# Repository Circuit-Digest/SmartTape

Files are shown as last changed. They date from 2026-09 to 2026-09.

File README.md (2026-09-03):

# SmartTape - Digital Measuring Tool

```
  ███████╗███╗   ███╗ █████╗ ██████╗ ████████╗    ████████╗ █████╗ ██████╗ ███████╗
  ██╔════╝████╗ ████║██╔══██╗██╔══██╗╚══██╔══╝    ╚══██╔══╝██╔══██╗██╔══██╗██╔════╝
  ███████╗██╔████╔██║███████║██████╔╝   ██║          ██║   ███████║██████╔╝█████╗  
  ╚════██║██║╚██╔╝██║██╔══██║██╔══██╗   ██║          ██║   ██╔══██║██╔═══╝ ██╔══╝  
  ███████║██║ ╚═╝ ██║██║  ██║██║  ██║   ██║          ██║   ██║  ██║██║     ███████╗
  ╚══════╝╚═╝     ╚═╝╚═╝  ╚═╝╚═╝  ╚═╝   ╚═╝          ╚═╝   ╚═╝  ╚═╝╚═╝     ╚══════╝
```







A pocket-size multi-mode digital laser measuring tape device built around the **STM32G491CEU6** 32-bit ARM Cortex-M4F microcontroller. Featuring **ST VL53L4CX 6.0-meter Time-of-Flight (ToF) ranging**, **Murata SCL3300 3-axis inclinometer level sensing**, an **animated 60FPS smartwatch-style carousel UI**, and **non-volatile internal Flash memory persistence**.

---

## Key Features

* **8 Comprehensive Operating Modes**:
  1. **Distance Meter (`DIST`)**: Real-time continuous ToF distance measurement (up to 6.0 meters / 600 cm) with live roll & pitch level alignment bars.
  2. **Spirit Level (`LEVEL`)**: 2D digital bubble level + 3D pitch/roll angle readout ($0.01^\circ$ resolution) and temperature display.
  3. **Height Meter (`HEIGHT`)**: Pythagoras indirect height measurement with automatic ToF vertical mounting offset & 2-point empirical tilt calibration.
  4. **Area Calculator (`AREA`)**: 2-shot interactive room area calculation ($L \times W \implies \text{cm}^2 / \text{m}^2$).
  5. **Volume Calculator (`VOLUME`)**: 3-shot 3D space volume calculation ($L \times W \times H \implies \text{cm}^3 / \text{m}^3$).
  6. **Cylinder Meter (`CYLINDER`)**: Pipe and tank volume calculation ($\pi \cdot R^2 \cdot H$).
  7. **Max / Min Tracker (`MAXMIN`)**: Dynamic real-time minimum and maximum distance boundary tracker.
  8. **Memory Log (`MEMORY`)**: Persistent 10-slot measurement record buffer.

* **ST VL53L4CX Ranging Optimization**:
  - **Multi-Target Histogram Ranging**: Penetrates transparent glass windows and filters out foreground obstacles to lock onto background target walls.
  - **Cover Glass Crosstalk Cancellation**: Cancels internal VCSEL reflections inside protective enclosure windows.

* **Power Management & Dual Auto-Wakeup**:
  - Hardware `XSHUT` zero-current shutdown.
  - 3-Minute Inactivity Auto-Sleep.
  - SCL3300 Motion Pick-up ($\Delta G > 0.03g$) & Encoder Turn/Press instant auto-wakeup.

---

## User Controls & Navigation Guide

### 1. Hardware Controls Overview
- **Rotary Encoder Knob (Hongyan RS11)**: Spring-return $\pm 15^\circ$ rotation knob (flicks CW / CCW and snaps back to center).
- **Center Push Button Switch (SW)**: Integrated tactile push-button (`PB14`).

---

### 2. Main Screen & Measurement Navigation

| Action / Gesture | Hardware Trigger | Mode / Context | Function / Operation |
| :--- | :--- | :--- | :--- |
| **Rotate Knob (CW / CCW)** | Flick Knob $\pm 15^\circ$ | **Carousel Menu** | Scroll through 8 measurement modes (smooth 60FPS animation). |
| **Rotate Knob (CW / CCW)** | Flick Knob $\pm 15^\circ$ | **Memory Log (`MEMORY`)** | Browse through 10 saved measurement history records. |
| **Single-Press** | Press Button | **Carousel Menu** | **Select & Enter** highlighted measurement mode. |
| **Single-Press** | Press Button | **`DIST` / `HEIGHT` Modes** | **Toggle `HOLD` Mode** (freezes measurement reading & angle; turns OFF laser). |
| **Single-Press** | Press Button | **`AREA` Mode** | Take Shot 1 (Length) $\rightarrow$ Take Shot 2 (Width) $\rightarrow$ Calculate Area ($\text{cm}^2 / \text{m}^2$). |
| **Single-Press** | Press Button | **`VOLUME` Mode** | Take Shot 1 (Length) $\rightarrow$ Shot 2 (Width) $\rightarrow$ Shot 3 (Height) $\rightarrow$ Calculate Volume ($\text{cm}^3 / \text{m}^3$). |
| **Single-Press** | Press Button | **`MAXMIN` Mode** | Reset Min / Max distance trackers. |
| **Double-Press** | Quick 2x Click ($< 400\text{ms}$) | **Any Mode / Settings** | **Global BACK** $\rightarrow$ Return immediately to Main Carousel Menu. |
| **Long-Press** | Hold Button ($> 800\text{ms}$) | **Any Screen** | **Toggle Settings Menu** overlay. |
| **Press + Twist** | Hold Switch + Rotate Knob | **Any Active Mode** | **Chorded Gesture BACK** $\rightarrow$ Return immediately to Main Carousel Menu. |

---

### 3. Settings Menu Navigation & Value Editing

```
[Main Carousel] ──(Long-Press >800ms)──> [Settings Overlay]
                                                │
                          Rotate Knob ───> Scroll items (UNIT, DATUM, OFFSET)
                                                │
                          Single-Press ──> Enter ITEM EDIT MODE (SETTINGS [EDIT])
                                                │
                          Rotate Knob ───> Fast-adjust value (0.1cm steps for offset)
                                                │
                    Single or Double-Press ─> Confirm & Auto-Save to Flash Page 255
```

| Action / Gesture | Context | Function |
| :--- | :--- | :--- |
| **Rotate Knob** | Settings List Mode | Scroll between items (`0: UNIT`, `1: DATUM`, `2: REAR OFFSET`). |
| **Single-Press** | Settings List Mode | Enter **ITEM EDIT MODE** (`SETTINGS [EDIT]`). Value displays in `< angle brackets >`. |
| **Rotate Knob** | **ITEM EDIT MODE** | **Change Value**: <br>• **`UNIT`**: `CM` $\leftrightarrow$ `MM` $\leftrightarrow$ `M` $\leftrightarrow$ `INCH` <br>• **`DATUM`**: `REAR` $\leftrightarrow$ `FRONT` <br>• **`OFFSET`**: Adjust body length in **0.1 cm (1 mm)** steps! |
| **Single-Press** | **ITEM EDIT MODE** | Confirm new value, **Save to NVM Flash Page 255**, and return to Settings List. |
| **Double-Press** | **ITEM EDIT MODE** | Confirm value, Save to Flash, and return to Settings List. |
| **Double-Press** | Settings List Mode | Exit Settings and return to Main Carousel Menu. |

---

## Hardware Pinout Mapping

| Component | Signal | STM32G4 Pin | Description |
| :--- | :--- | :--- | :--- |
| **MCU** | Main Core | STM32G491CEU6 | 170 MHz ARM Cortex-M4F, 512KB Flash, 128KB RAM |
| **OLED Display** | I2C2 SDA | `PA8` | 1.3" 128x64 SH1106 OLED (Address `0x3C`) |
| | I2C2 SCL | `PA9` | |
| **ToF Sensor** | I2C1 SCL | `PA15` | ST VL53L4CX 6.0m ToF Sensor (Address `0x52`) |
| | I2C1 SDA | `PB7` | |
| | ToF INT | `PC10` | Hardware Interrupt Line |
| | ToF XSHUT | `PC11` | Hardware Zero-Power Shutdown Control |
| **Inclinometer** | SPI1 CS | `PA3` | Murata / VTI SCL3300 3-Axis Inclinometer |
| | SPI1 SCK | `PA5` | SPI Clock |
| | SPI1 MISO | `PA6` | SPI Master In Slave Out |
| | SPI1 MOSI | `PA7` | SPI Master Out Slave In |
| **Laser Diode** | EN | `PA4` | CAT4002A Constant-Current Laser Driver |
| **Battery Monitor**| ADC3 CH1 | `PB1` | 1S Li-Ion Voltage Divider ($100\text{ k}\Omega / 100\text{ k}\Omega$) |
| **Rotary Encoder** | SW | `PB14` | Hongyan RS11 Spring-Return Switch |
| | Phase A | `PB12` | Encoder Phase A |
| | Phase B | `PB13` | Encoder Phase B |

---

## Software & Driver Architecture

- **Toolchain**: STM32CubeIDE (GCC ARM Embedded Toolchain).
- **HAL Drivers**: STM32G4 HAL Driver Package + ST VL53L4CX Ultra-Lite Driver (ULD).
- **Core Files**:
  - `Core/Src/main.c`: Main firmware logic, state machine, ToF filtering, calibration, and Flash storage.
  - `Core/Src/oled.c`: SH1106 OLED vector graphics, 7-segment font renderer, and 60FPS carousel engine.
  - `Core/Src/scl3300.c`: SPI driver and angle/acceleration conversion for Murata SCL3300.

---

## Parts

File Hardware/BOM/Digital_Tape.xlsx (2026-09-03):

Name | Description | Designator | Footprint | LibRef | Quantity
10 µF | CAP0603 X7R 10UF 20% 6.3V | C1, C3, C5, C14, C25 | CAP 0603_1608 | GMC10X7R106M6R3NT | 5
0.1 µF | CAP CER 0.1UF 16V X7R 0603 | C2, C4, C6, C7, C10, C12, C15, C16, C17, C18, C21, C22, C23, C24 | CAP 0603_1608 | CS0603KRX7R7BB104 | 14
1µF | CAP CER 1UF 10V Y5V 0603 | C8, C9, C11, C13, C26, C27 | CAP 0603_1608 | 0603ZG105ZAT2A | 6
8 pF | CAP CER 8PF 50V 0603 EPOXY | C19, C20 | CAP 0603_1608 | CGA3E2C0G1H080D080AD | 2
CUS10S30,H3F | DIODE SCHOTTKY 30V 1A USC | D1 | SOD323 | CUS10S30,H3F | 1
GG0402060R3C2P | TVS DIODE 6.5VWM 15.5VC 0402 | D2, D3 | 0402 | GG0402060R3C2P | 2
DIM_PAD |  | DP1, DP2 | DIM_PAD | DIM_PAD | 2
OLED_128X64_1.3_I2C | Non-Touch Graphic LCD Display Module Transmissive White OLED, Monochrome I2C 1.3 (33.02mm) 128 x 64 | DS1 | LCD_OLED_128X64_1.3_I2C | OLED_128X64_1.3_I2C | 1
TYPE-C_16PIN_2MD_(073) | DC-5V 5A Type C USB | J1 | SHOUHAN_TYPE-C_16PIN_2MD_(073) | TYPE-C_16PIN_2MD_(073) | 1
B2B-PH-K-S(LF)(SN) | Connector Header Through Hole 2 position 0.079 (2.00mm) | J2 | JST_B2B-PH-K-S(LF)(SN) | B2B-PH-K-S(LF)(SN) | 1
TSHC-103-D-171-16-264-F-LF | 6 Position Dual Row (3x2) 2.54mm Pitch Non-Shrouded Header | J3 | MLE_TSHC-103-D-171-16-264-F-LF | TSHC-103-D-171-16-264-F-LF | 1
RLD65NZN5 |  | LD1 | RLD65NZN5 | RLD65NZN5 | 1
PEC11R-4215F-S0024 | Incremental Encoder, 12 Mm, Contact Rating 10 Ma - 5 Vdc | MT1 | XDCR_PEC11R-4215F-S0024 | PEC11R-4215F-S0024 | 1
AO3401A | P-Channel MOSFET, 30 V, 4 A, -55 to 150 degC, 3-Pin SOT-23-3L, RoHS, Tape and Reel | Q1 | AO-SOT-23-3L_V | CMP-2000-05778-1 | 1
0 Ohms | RES SMD 56K OHM 0.1% 1/10W 0603, RES 0 OHM JUMPER 1/10W 0603 | R1, R10 | RES 0603_1608 | RT0603BRD0756KL, PA0603-R-070RL | 2
1 kOhms | RES SMD 1K OHM 0.1% 1/16W 0603 | R2, R9, R17 | RES 0603_1608 | CPF0603B1K0E | 3
10 kOhms | RES 10K OHM 0.1% 1/16W 0603 | R3, R8, R11, R13, R14, R15, R16 | RES 0603_1608 | RNCS0603BKE10K0 | 7
10 kOhms | RES SMD 10K OHM 0.1% 1/16W 0402 | R4 | RES 0402_1005 | RT0402BRE0710KL | 1
5.1 kOhms | RES 5.1K OHM 5% 1/10W 0603 | R5, R7 | RES 0603_1608 | RMCF0603JG5K10 | 2
100 kOhms | RES 100K OHM 0.1% 1/16W 0603 | R6, R18, R19 | RES 0603_1608 | RNCS0603BKE100K | 3
1.65 kOhms | RES 1.65K OHM 1% 1/10W 0603 | R12 | RES 0603_1608 | RC0603FR-071K65L | 1
3.74 kOhms | RES 3.74K OHM 0.5% 1/10W 0603 | R20 | RES 0603_1608 | RNCF0603DTE3K74 | 1
4.7 kOhms | RES 4.7K OHM 0.1% 1/5W 0603 | R21, R22 | RES 0603_1608 | RS73G1JTTD4701B | 2
EG1215AA | Slide Switch SPDT Surface Mount, Right Angle | S1 | SW_EG1215AA | EG1215AA | 1
TS-1088-AR02016 |  | SW1, SW2 | SW-SMD_L3.9-W3.0-P4.45 | TS-1088-AR02016 | 2
ROUND PAD 1.5MM |  | TP1, TP2 | ROUND PAD 1.5MM | ROUND PAD 1.5MM | 2
LD39200PU33R | 2 A high PSRR ultra low drop linear regulator with reverse current protection | U1 | SON_DFN6_3X3_STM | LD39200PU33R | 1
LTC4057ES5-4.2 | Linear Li-Ion Battery Charger with Thermal Regulation in ThinSOT | U2 | S_5_ADI | LTC4057ES5-4.2TRMPBF | 1
STM32G491CEU6 | Mainstream Arm Cortex-M4 MCU 170 MHz with 512 Kbytes of Flash memory, Math Accelerator, High Analog level integration | U3 | QFPN_491CEU6_STM | STM32G491CEU6 | 1
SCL3300-D01-10 | Description | U4 | SCL3300-D01-10_MUR | SCL3300-D01-10 | 1
VL53L4CXV0DH/1 | Time-of-Flight (ToF) sensor with extended range measurement | U5 | LGA12_STM | VL53L4CXV0DH1 | 1
CAT4002A | 12-bit, single-channel, ultra-low power DAC in 6-pin SC70 package for battery powered applications | U6 | CAT4002A | CAT4002A | 1
ECS-240-8-37B-CKY-TR | 24 MHz Â±10ppm Crystal 8pF 50 Ohms 4-SMD, No Lead | Y1 | XTAL_ECS-160-9-37-CKM-TR | ECS-240-8-37B-CKY-TR | 1

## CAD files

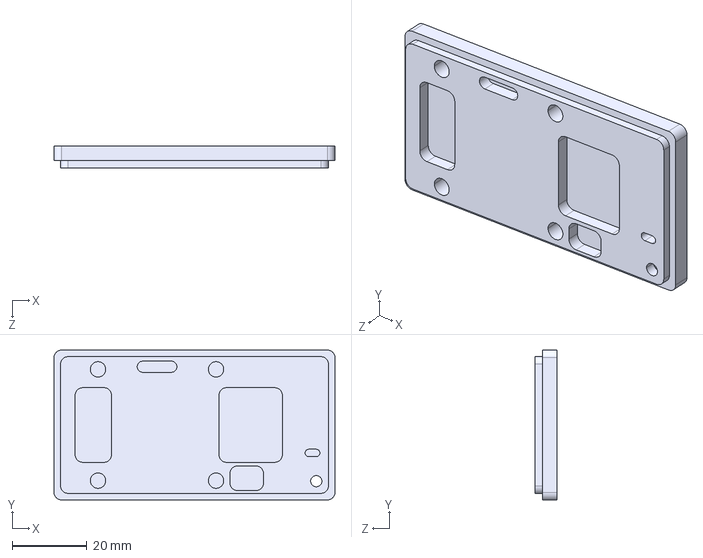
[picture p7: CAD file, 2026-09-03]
Hardware/CAD/SmartTape_BottomV1.STEP
75.0 x 40.0 x 6.00 mm

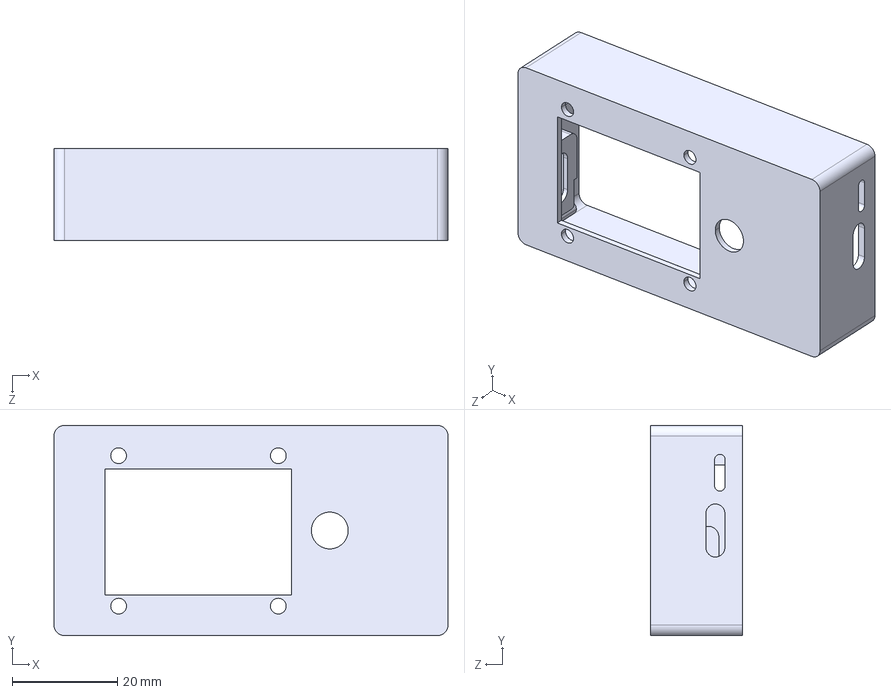
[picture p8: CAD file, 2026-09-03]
Hardware/CAD/SmartTape_TopV2.STEP
75.0 x 40.0 x 17.5 mm

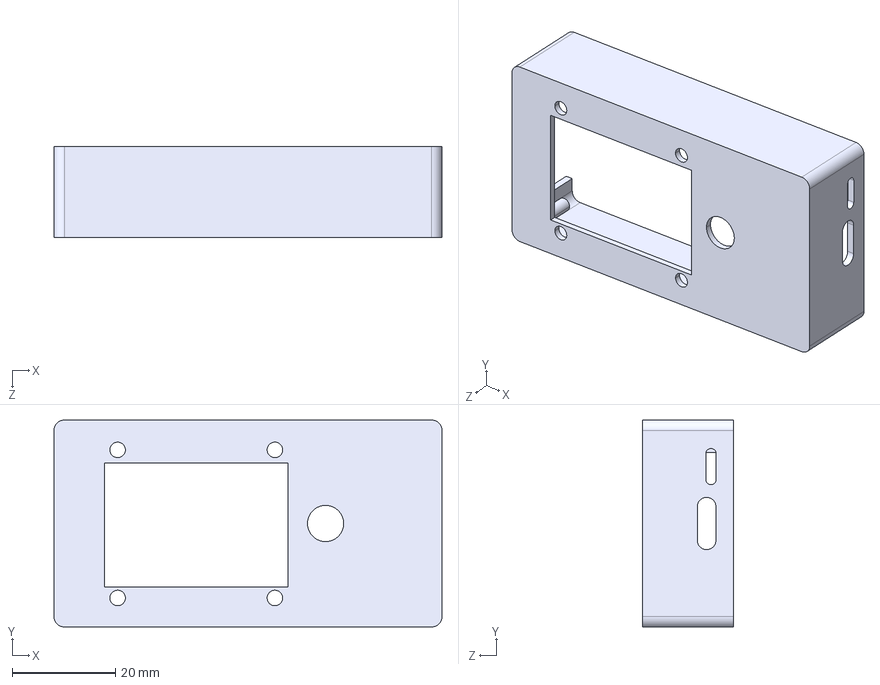
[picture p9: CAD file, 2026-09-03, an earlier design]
Hardware/CAD/SmartTape_TopV1.STEP
75.0 x 40.0 x 17.5 mm

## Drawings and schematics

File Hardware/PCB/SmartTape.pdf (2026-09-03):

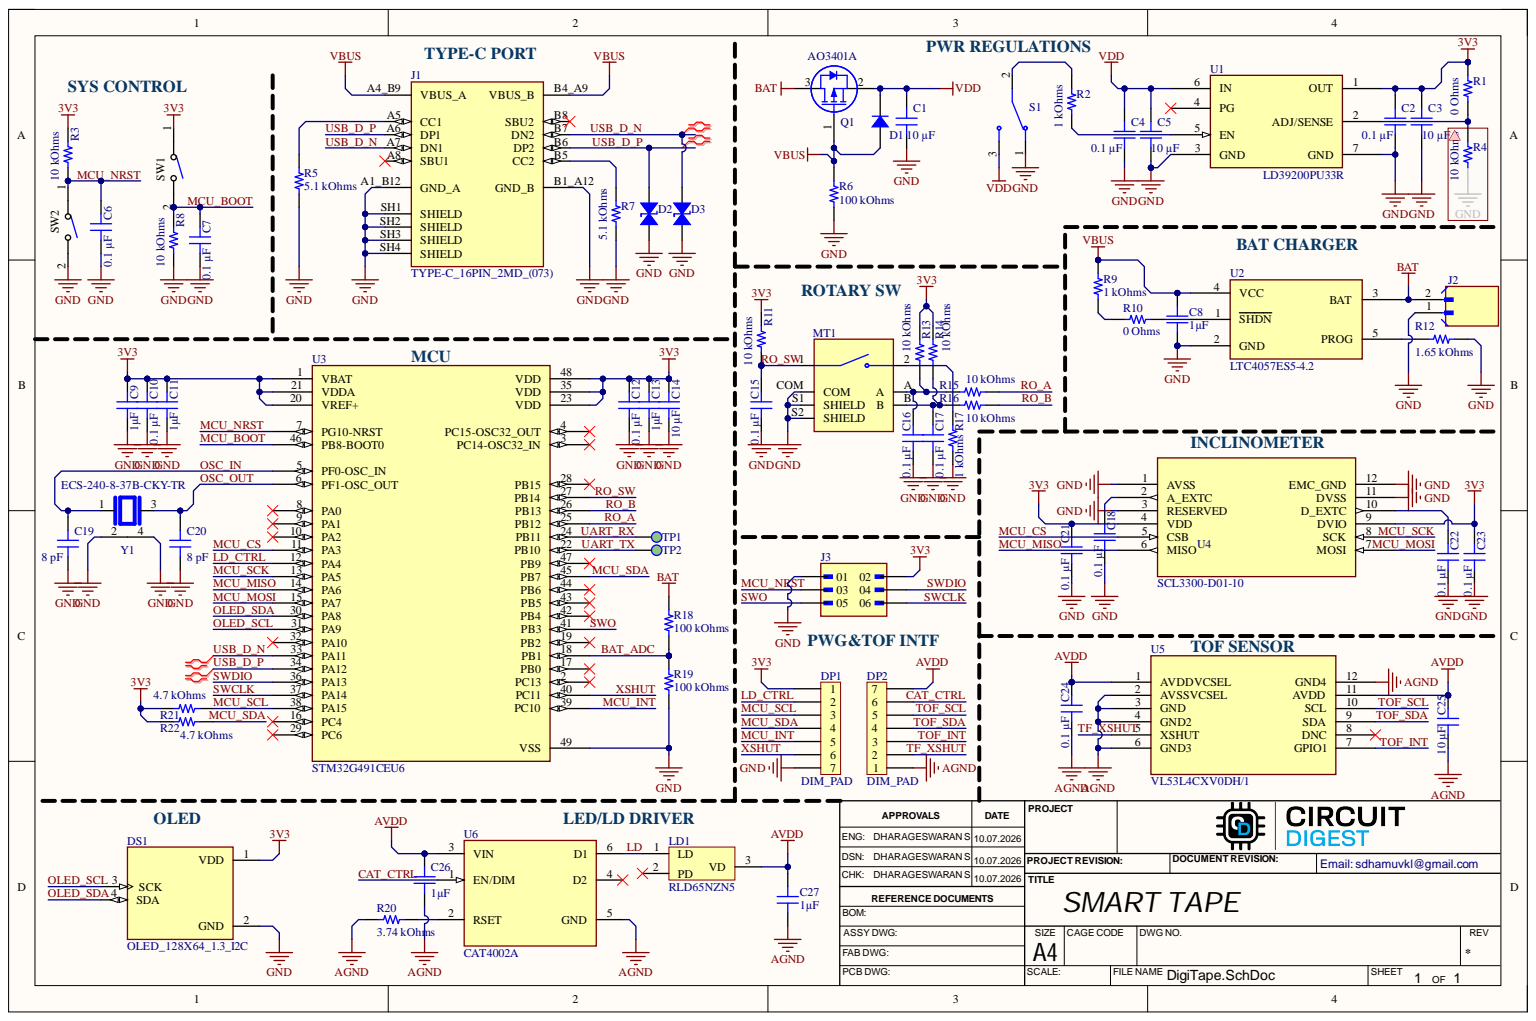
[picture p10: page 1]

DATE | PROJ E C T APPROVALS

ENG : DHARAGE S WA R AN S | 1 0.0 7.2 0 2 6

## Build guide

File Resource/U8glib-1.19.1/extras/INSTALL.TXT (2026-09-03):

U8GLIB
http://code.google.com/p/u8glib/

Install instructions for the Arduino environment.

  1. Start Arduino IDE
  2. In the Arduino IDE, import the library from the "Add Library" Menu.

Alternative install instructions for the Arduino environment.

  1. Unzip u8glib_arduino_vX.XX.zip into the "libraries" folder of the
      Arduino install directory
  2. Start Arduino IDE

Install instructions for the Chipkit (Arduino) environment.

  1. cd <mpide-... path>/libraries
  2. unzip u8glib_arduino_vX.XX.zip
  3. cd <mpide-... path>///hardware/pic32/libraries
  4. again: u8glib_arduino_vX.XX.zip
  5. Open hardware/pic32/cores/pic32/Print.h
	  Remove line
	    #define BYTE 0
	  from the file, use PRINT_BYTE instead of BYTE.

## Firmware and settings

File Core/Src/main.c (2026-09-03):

/*
 * main.c
 * Main firmware implementation for SmartTape Tool
 *
 * Copyright (c) 2026 Dharagesh and Circuit Digest
 * https://github.com/Circuit-Digest/SmartTape
 * Licensed under GNU General Public License v3.0
 */

/*
  ███████╗███╗   ███╗ █████╗ ██████╗ ████████╗    ████████╗ █████╗ ██████╗ ███████╗
  ██╔════╝████╗ ████║██╔══██╗██╔══██╗╚══██╔══╝    ╚══██╔══╝██╔══██╗██╔══██╗██╔════╝
  ███████╗██╔████╔██║███████║██████╔╝   ██║          ██║   ███████║██████╔╝█████╗  
  ╚════██║██║╚██╔╝██║██╔══██║██╔══██╗   ██║          ██║   ██╔══██║██╔═══╝ ██╔══╝  
  ███████║██║ ╚═╝ ██║██║  ██║██║  ██║   ██║          ██║   ██║  ██║██║     ███████╗
  ╚══════╝╚═╝     ╚═╝╚═╝  ╚═╝╚═╝  ╚═╝   ╚═╝          ╚═╝   ╚═╝  ╚═╝╚═╝     ╚══════╝
*/
/**
  ******************************************************************************
  * @file           : main.c
  * @brief          : Main program body - Digital Measurement Device
  *                   Modes: DIST, LEVEL, HEIGHT, AREA, VOLUME, CYLINDER, MAX/MIN, MEMORY
  ******************************************************************************
  */
/* Includes ------------------------------------------------------------------*/
#include "main.h"
#include "usb_device.h"

/* USER CODE BEGIN Includes */
#include "usbd_cdc_if.h"
#include <stdio.h>
#include <math.h>
#include "scl3300.h"
#include "vl53lx_api.h"
#include "oled.h"
#include <stdbool.h>
#include <string.h>
/* USER CODE END Includes */

/* USER CODE BEGIN PTD */
typedef struct {
    int32_t  counter;
    uint8_t  prev_a;
    uint8_t  prev_b;
    uint8_t  prev_sw;
    uint32_t press_start_tick;
    uint32_t last_turn_tick;
    bool     short_press;
    bool     long_press;
    bool     long_press_handled;
    bool     press_twist; // Press + Twist chorded gesture flag (Switch held while turning knob)
} Encoder_t;

typedef enum {
    APP_STATE_MENU = 0,
    APP_STATE_MEASURE,
    APP_STATE_SETTINGS
} AppState_t;
/* USER CODE END PTD */

/* USER CODE BEGIN PD */
#define DEG_TO_RAD(deg) ((deg) * 0.017453292519943295f)
#define M_PI_F 3.14159265358979323846f
#define DOUBLE_PRESS_WINDOW_MS 400
#define TOF_VERTICAL_OFFSET_CM 2.4f // 1.8cm optical center + 0.6cm enclosure base = 2.4cm total vertical mounting offset
#define HEIGHT_GAIN_SCALE      1.0989f // 2-point empirical calibration slope gain
#define HEIGHT_BIAS_OFFSET     +2.242f // +4.0cm offset shift correction (36.0cm -> 40.0cm exact match)
/* USER CODE END PD */

ADC_HandleTypeDef hadc3;

I2C_HandleTypeDef hi2c1;
I2C_HandleTypeDef hi2c2;

SPI_HandleTypeDef hspi1;

UART_HandleTypeDef huart3;

/* USER CODE BEGIN PV */
OLED_HandleTypeDef       oled_dev;
SCL3300_HandleTypeDef    scl_dev;
VL53LX_Dev_t             vl53_dev_inst;
VL53LX_DEV               vl53_dev = &vl53_dev_inst;
VL53LX_DEV               p_vl53 = &vl53_dev_inst;

Encoder_t             encoder = {0};

uint8_t  selected_mode = 0;       // Highlighted item in 4x2 Menu Grid (0..7)
AppState_t app_state = APP_STATE_MENU; // Global app state
bool     in_settings = false;     // Full-screen Settings overlay active
bool     in_settings_edit = false;// Settings Parameter Value Edit Mode active
uint8_t  settings_item = 0;       // 0: Unit, 1: Datum, 2: Rear Offset

uint8_t  unit_mode = 0;           // 0: CM, 1: MM, 2: M, 3: INCH
uint8_t  datum_mode = 0;          // 0: REAR (bottom), 1: FRONT (top)
float    rear_offset_cm = 6.6f;   // 6.6 cm device body length offset when REAR datum selected

bool     laser_active = false;
uint32_t last_short_press_tick = 0; // For global double-press detection

float    laser_pitch_elev = 0.0f;   // Global Laser Pitch Elevation (-Angle X)
float    side_roll = 0.0f;          // Global Screen Side Roll (Angle Y)
int16_t  carousel_anim_x = 0;       // Smooth sliding animation offset for fitness band carousel menu

// Auto Sleep & Motion Wakeup Control
#define AUTO_SLEEP_TIMEOUT_MS  180000UL // 3 Minutes (180 Seconds) Inactivity Timeout
bool     device_sleeping = false;
uint32_t last_activity_tick = 0;
float    prev_acc_x = 0.0f;
float    prev_acc_y = 0.0f;
float    prev_acc_z = 0.0f;

bool     hold_active = false;
int      hold_distance_mm = -1;
float    hold_pitch_elev = 0.0f;

float    min_dist_cm = 9999.0f;
float    max_dist_cm = 0.0f;

bool     boot_complete = false;
uint32_t blink_tick = 0;
bool     blink_on = true;

// Multi-shot measurement accumulators for area, volume, height, cylinder
uint8_t  multi_shot_step = 0;
float    shot1_cm = -1.0f;
float    shot2_cm = -1.0f;
float    shot3_cm = -1.0f;

// Saved History Storage (last 10 measurements)
#define MAX_HISTORY 10
float    history_val[MAX_HISTORY];
float    history_buffer[MAX_HISTORY];
uint8_t  history_mode[MAX_HISTORY];
uint8_t  history_unit[MAX_HISTORY];
uint8_t  history_count = 0;
uint8_t  history_view_idx = 0;

/* USER CODE END PV */

void SystemClock_Config(void);
static void MX_GPIO_Init(void);
static void MX_I2C1_Init(void);
static void MX_I2C2_Init(void);
static void MX_SPI1_Init(void);
static void MX_USART3_UART_Init(void);
static void MX_ADC3_Init(void);
/* USER CODE BEGIN PFP */
float Read_Battery_Voltage(void);
uint8_t Calculate_Battery_Percentage(float v_bat);
void Format_Distance_String(float dist_cm, uint8_t unit, char *out_str, size_t max_len);
void Add_To_History(float dist_cm);
void Save_Settings_To_Flash(void);
void Load_Settings_From_Flash(void);
/* USER CODE END PFP */

/* USER CODE BEGIN 0 */
void Encoder_Init(Encoder_t *e)
{
    e->counter = 0;
    e->prev_a = HAL_GPIO_ReadPin(GPIOB, GPIO_PIN_12);
    e->prev_b = HAL_GPIO_ReadPin(GPIOB, GPIO_PIN_13);
    e->prev_sw = HAL_GPIO_ReadPin(GPIOB, GPIO_PIN_14);
    e->press_start_tick = 0;
    e->last_turn_tick = 0;
    e->short_press = false;
    e->long_press = false;
    e->long_press_handled = false;
}

void Reset_Multi_Shot(void)
{
    multi_shot_step = 0;
    shot1_cm = -1.0f;
    shot2_cm = -1.0f;
    shot3_cm = -1.0f;
}

void Encoder_Update(Encoder_t *e)
{
    // 1. Read Quadrature / Spring-Return Encoder Pins (Hongyan RS11: A = PB12, B = PB13)
    uint8_t curr_a = HAL_GPIO_ReadPin(GPIOB, GPIO_PIN_12);
    uint8_t curr_b = HAL_GPIO_ReadPin(GPIOB, GPIO_PIN_13);

    uint32_t now = HAL_GetTick();
    int dir = 0;

    // Dual-edge detection with 150ms spring-return lockout for Hongyan RS11 (+15 deg CW / -15 deg CCW toggle switch)
    if (now - e->last_turn_tick >= 150) {
        if (e->prev_a == GPIO_PIN_SET && curr_a == GPIO_PIN_RESET) {
            dir = (curr_b == GPIO_PIN_SET) ? 1 : -1;
            e->last_turn_tick = now;
        } else if (e->prev_b == GPIO_PIN_SET && curr_b == GPIO_PIN_RESET) {
            dir = (curr_a == GPIO_PIN_SET) ? -1 : 1;
            e->last_turn_tick = now;
        }
    }

    uint8_t curr_sw = HAL_GPIO_ReadPin(GPIOB, GPIO_PIN_14);

    if (dir != 0) {
        if (curr_sw == GPIO_PIN_RESET) {
            // Press + Twist chorded gesture detected! (Switch held while twisting encoder)
            e->press_twist = true;
            e->long_press_handled = true; // Prevent triggering short press on release
            printf("\r\n>>> [GESTURE DETECTED] Switch Held + Encoder Twist! <<<\r\n\r\n");
        } else {
            e->counter += dir;

            if (app_state == APP_STATE_SETTINGS || in_settings) {
                if (in_settings_edit) {
                    // ITEM EDIT MODE: Turning Encoder Changes Selected Parameter Value
                    if (settings_item == 0) { // UNIT MODE (0: CM, 1: MM, 2: M, 3: INCH)
                        int u = (int)unit_mode + dir;
                        if (u < 0) u = 3;
                        if (u > 3) u = 0;
                        unit_mode = (uint8_t)u;
                    } else if (settings_item == 1) { // DATUM MODE (0: REAR, 1: FRONT)
                        datum_mode = (datum_mode == 0) ? 1 : 0;
                    } else if (settings_item == 2) { // REAR OFFSET (0.0cm .. 20.0cm in 0.1cm steps)
                        rear_offset_cm += (dir > 0) ? 0.1f : -0.1f;
                        if (rear_offset_cm < -0.01f) rear_offset_cm = 20.0f;
                        if (rear_offset_cm > 20.01f) rear_offset_cm = 0.0f;
                    }
                } else {
                    // MENU NAVIGATION MODE: Scroll through 3 Settings Items (0: Unit, 1: Datum, 2: Rear Offset)
                    int item = (int)settings_item + dir;
                    if (item < 0) item = 2;
                    if (item > 2) item = 0;
                    settings_item = (uint8_t)item;
                }
            } else if (app_state == APP_STATE_MENU) {
                // Scroll through all 8 available modes in fitness band carousel
                int m = (int)selected_mode + dir;
                if (m < 0) m = 7;
                if (m > 7) m = 0;
                selected_mode = (uint8_t)m;
                carousel_anim_x = (dir > 0) ? 36 : -36;
            } else if (app_state == APP_STATE_MEASURE && selected_mode == 7) {
                // In History Memory Mode, scroll through saved records
                if (history_count > 0) {
                    int h_idx = (int)history_view_idx + dir;
                    if (h_idx < 0) h_idx = history_count - 1;
                    if (h_idx >= history_count) h_idx = 0;
                    history_view_idx = (uint8_t)h_idx;
                }
            }

            printf("\r\n>>> [ENCODER BUMP] Dir: %d | Counter: %ld | Mode: %u | Settings Item: %u <<<\r\n\r\n",
                   dir, (long)e->counter, selected_mode, settings_item);
        }
    }

    e->prev_a = curr_a;
    e->prev_b = curr_b;

    // 2. Short-Press & Long-Press Detection

    // Button Pressed Down
    if (e->prev_sw == GPIO_PIN_SET && curr_sw == GPIO_PIN_RESET) {
        e->press_start_tick = HAL_GetTick();
        e->long_press_handled = false;
    }

    // Button Held Down (Check for Long Press > 800ms)
    if (curr_sw == GPIO_PIN_RESET && !e->long_press_handled) {
        if (HAL_GetTick() - e->press_start_tick >= 800) {
            e->long_press = true;
            e->long_press_handled = true;
        }
    }

    // Button Released
    if (e->prev_sw == GPIO_PIN_RESET && curr_sw == GPIO_PIN_SET) {
        uint32_t press_duration = HAL_GetTick() - e->press_start_tick;
        if (press_duration >= 50 && press_duration < 800 && !e->long_press_handled) {
            e->short_press = true;
        }
    }

    e->prev_sw = curr_sw;

    if (dir != 0 || e->short_press || e->long_press || curr_sw == GPIO_PIN_RESET) {
        last_activity_tick = now;
        if (device_sleeping) {
            device_sleeping = false;
            OLED_DisplayOn(&oled_dev);
            HAL_GPIO_WritePin(GPIOC, GPIO_PIN_11, GPIO_PIN_SET); // Hardware XSHUT Power ON (PC11)
            if (p_vl53) VL53LX_StartMeasurement(p_vl53);
            printf(" -> [WAKEUP] Encoder Interaction! Display & ToF Active.\r\n");
        }
    }
}

// --- Distance-Adaptive Long-Range Moving Median & EMA Filter ---
#define TOF_FILTER_WINDOW 7
static int     tof_window_buf[TOF_FILTER_WINDOW] = {0};
static uint8_t tof_window_idx = 0;
static uint8_t tof_window_count = 0;
static float   filtered_tof_mm = -1.0f;

int Filter_ToF_Distance_MM(int raw_mm)
{
    if (raw_mm <= 0) return (int)filtered_tof_mm;

    // 1. Add sample to sliding window buffer
    tof_window_buf[tof_window_idx] = raw_mm;
    tof_window_idx = (tof_window_idx + 1) % TOF_FILTER_WINDOW;
    if (tof_window_count < TOF_FILTER_WINDOW) tof_window_count++;

    // 2. Selection sort to find Median (outlier spike rejection)
    int sorted[TOF_FILTER_WINDOW];
    for (uint8_t i = 0; i < tof_window_count; i++) sorted[i] = tof_window_buf[i];

    for (uint8_t i = 0; i < tof_window_count - 1; i++) {
        for (uint8_t j = i + 1; j < tof_window_count; j++) {
            if (sorted[i] > sorted[j]) {
                int tmp = sorted[i];
                sorted[i] = sorted[j];
                sorted[j] = tmp;
            }
        }
    }

    int median_mm = sorted[tof_window_count / 2];

    // 3. Distance-Adaptive EMA Filter Weight
    // At short range (500mm): alpha = 0.60 (Fast response)
    // At long range (4000mm): alpha = 0.23 (Damped steady)
    float alpha = 1.0f / (1.0f + 0.0008f * (float)median_mm);
    if (alpha < 0.08f) alpha = 0.08f;
    if (alpha > 0.60f) alpha = 0.60f;

    if (filtered_tof_mm < 0.0f) {
        filtered_tof_mm = (float)median_mm; // Seed initial value
    } else {
        filtered_tof_mm = (alpha * (float)median_mm) + ((1.0f - alpha) * filtered_tof_mm);
    }

    return (int)(filtered_tof_mm + 0.5f);
}

// --- ST Multi-Target Histogram & Signal Quality Evaluator ---
float live_signal_mcps  = 0.0f;
float live_ambient_mcps = 0.0f;
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
int main(void)
{

  /* MCU Configuration--------------------------------------------------------*/

  /* Reset of all peripherals, Initializes the Flash interface and the Systick. */
  HAL_Init();

  /* Configure the system clock */
  SystemClock_Config();

  /* Initialize all configured peripherals */
  MX_GPIO_Init();
  MX_ADC3_Init();
  MX_I2C1_Init();
  MX_I2C2_Init();
  MX_SPI1_Init();
  MX_USART3_UART_Init();
  MX_USB_Device_Init();

  /* USER CODE BEGIN 2 */
  // 1. Initial State: Keep CAT4002A EN (PA4) LOW (Laser OFF)
  HAL_GPIO_WritePin(GPIOA, GPIO_PIN_4, GPIO_PIN_RESET);

  // 2. Calibrate ADC3 for accurate battery voltage readings on PB1
  HAL_ADCEx_Calibration_Start(&hadc3, ADC_SINGLE_ENDED);

  // 3. Initialize Rotary Encoder (SW: PB14, A: PB12, B: PB13)
  Encoder_Init(&encoder);

  // 4. Hardware Reset & Boot Pulse for VL53L4CX via PC11 (XSHUT)
  HAL_GPIO_WritePin(GPIOC, GPIO_PIN_11, GPIO_PIN_RESET); // Hold XSHUT low
  HAL_Delay(50);                                         // Hold reset low
  HAL_GPIO_WritePin(GPIOC, GPIO_PIN_11, GPIO_PIN_SET);   // Drive XSHUT high
  HAL_Delay(100);                                        // Boot delay for ToF internal MCU initialization

  // 5. Allow USB CDC port to enumerate on PC terminal
  HAL_Delay(1500);

  printf("\r\n===============================================\r\n");
  printf("  STM32G491 MEASURE METER DEMO   \r\n");
  printf("===============================================\r\n");

  // 6. Initialize OLED Display (I2C2 on PA8/PA9)
  printf("[INIT] Initializing 1.3\" OLED Display on I2C2 (PA8/PA9)...\r\n");
  bool oled_ok = OLED_Init(&oled_dev, &hi2c2);
  if (oled_ok) {
      printf(" -> [OK] 1.3\" OLED Display Initialized (Addr: 0x3C)\r\n");
      // Phase 1: Sweep line animation
      for (int sweep = 0; sweep < 128; sweep += 16) {
          OLED_Clear(&oled_dev);
          OLED_FillRect(&oled_dev, 0, 0, sweep + 16, 64, OLED_COLOR_WHITE);
          OLED_UpdateScreen(&oled_dev);
          HAL_Delay(25);
      }
      // Phase 2: Animated Digital Measuring Tape & Laser Splash Screen
      OLED_Clear(&oled_dev);

      // 1. Title Banner
      OLED_DrawStringLarge(&oled_dev, 4, 2, "SMART-TAPE", OLED_COLOR_WHITE);

      // 2. Digital Measuring Tape Ruler Ticks (Y: 18..28)
      OLED_DrawRect(&oled_dev, 4, 18, 120, 10, OLED_COLOR_WHITE);
      for (uint8_t tick_x = 8; tick_x <= 116; tick_x += 4) {
          uint8_t tick_h = ((tick_x - 8) % 16 == 0) ? 6 : 3;
          OLED_DrawLine(&oled_dev, tick_x, 18, tick_x, 18 + tick_h, OLED_COLOR_WHITE);
      }

      // 3. Laser Meter Body & Beam Animation (Y: 34..48)
      OLED_DrawRect(&oled_dev, 8, 34, 18, 14, OLED_COLOR_WHITE);
      OLED_DrawCircle(&oled_dev, 22, 41, 2, OLED_COLOR_WHITE);
      OLED_DrawRect(&oled_dev, 104, 33, 4, 16, OLED_COLOR_WHITE); // Target Wall

      for (uint8_t bx = 26; bx <= 100; bx += 6) {
          OLED_DrawLine(&oled_dev, 26, 41, bx, 41, OLED_COLOR_WHITE);
          OLED_DrawPixel(&oled_dev, bx + 2, 41, OLED_COLOR_WHITE);
          OLED_UpdateScreen(&oled_dev);
          HAL_Delay(35);
      }

      // 4. Impact Flash & Subtitle Banner
      OLED_DrawPixel(&oled_dev, 102, 39, OLED_COLOR_WHITE);
      OLED_DrawPixel(&oled_dev, 102, 43, OLED_COLOR_WHITE);
      OLED_DrawStringSmall(&oled_dev, 10, 53, "LOADING..." , OLED_COLOR_WHITE);
      OLED_UpdateScreen(&oled_dev);
      HAL_Delay(1200);
      boot_complete = true;
  } else {
      printf(" -> [WARN] OLED Display Not Detected on I2C2\r\n");
  }

  // 7. Initialize SCL3300 Inclinometer (SPI1)
  printf("[INIT] Initializing SCL3300 SPI1 (CS: PA3)...\r\n");
  bool scl_ok = SCL3300_Init(&scl_dev, &hspi1, GPIOA, GPIO_PIN_3, 4);
  if (scl_ok) {
      printf(" -> [OK] SCL3300 Initialized (WHOAMI: 0x%02X)\r\n", scl_dev.whoami);
  } else {
      printf(" -> [WARN] SCL3300 Init Warning (WHOAMI: 0x%02X)\r\n", scl_dev.whoami);
  }

  // 8. Initialize VL53L4CX Distance Sensor (I2C1)
  p_vl53->I2cHandle = &hi2c1;
  p_vl53->I2cDevAddr = 0x52; // 8-bit I2C Address

  printf("[INIT] Initializing VL53L4CX I2C1 (SCL: PA15, SDA: PB7)...\r\n");
  int vl53_status = VL53LX_WaitDeviceBooted(p_vl53);
  if (vl53_status == VL53LX_ERROR_NONE) {
      vl53_status = VL53LX_DataInit(p_vl53);
      if (vl53_status == VL53LX_ERROR_NONE) {
          // Configure ST internal APIs for 6.0m Maximum Range, High Accuracy & Crosstalk Cancellation
          VL53LX_SetDistanceMode(p_vl53, VL53LX_DISTANCEMODE_LONG);
          VL53LX_SetMeasurementTimingBudgetMicroSeconds(p_vl53, 200000); // 200ms integration time for max long-range sensitivity
          VL53LX_SetXTalkCompensationEnable(p_vl53, 1);                  // Enable Cover Glass Crosstalk Cancellation!

          vl53_status = VL53LX_StartMeasurement(p_vl53);
          if (vl53_status == VL53LX_ERROR_NONE) {
              printf(" -> [OK] VL53L4CX Active (LONG Mode, 200ms Budget, Crosstalk Comp ENABLED, 6m Max Range)\r\n");
          } else {
              printf(" -> [ERROR] VL53LX_StartMeasurement failed: %d\r\n", vl53_status);
          }
      } else {
          printf(" -> [ERROR] VL53LX_DataInit failed: %d\r\n", vl53_status);
      }
  } else {
      printf(" -> [ERROR] VL53LX_WaitDeviceBooted failed: %d\r\n", vl53_status);
  }

  // 9. Load Non-Volatile User Settings (Unit, Datum, Rear Offset) from STM32 Flash Page 255
  Load_Settings_From_Flash();
  last_activity_tick = HAL_GetTick();

  printf("===============================================\r\n");
  printf(" System Ready! Rotate Encoder / Press Button... \r\n");
  printf("===============================================\r\n\r\n");
  /* USER CODE END 2 */

  /* Infinite loop */
  /* USER CODE BEGIN WHILE */
  VL53LX_MultiRangingData_t ranging_data;
  uint8_t vl53_ready = 0;
  uint32_t sample_count = 0;
  uint32_t last_ui_tick = HAL_GetTick();

  while (1)
  {
    /* USER CODE END WHILE */

    /* USER CODE BEGIN 3 */
    uint32_t now = HAL_GetTick();

    // --- 1. Continuous Non-Blocking Polling of Rotary Encoder (SW: PB14, A: PB12, B: PB13) ---
    Encoder_Update(&encoder);

    // --- 2. Non-Blocking 33 Hz UI & Telemetry Timer (30 ms) ---
    if (now - last_ui_tick >= 30) {
        last_ui_tick = now;
        sample_count++;

        if (HAL_GetTick() - blink_tick >= 500) {
            blink_tick = HAL_GetTick();
            blink_on = !blink_on;
        }

        // --- Handle Long Press (> 800ms): Toggle Settings Menu Overlay ---
        if (encoder.long_press) {
            encoder.long_press = false;
            if (app_state == APP_STATE_SETTINGS || in_settings) {
                app_state = APP_STATE_MENU;
                in_settings = false;
            } else {
                app_state = APP_STATE_SETTINGS;
                in_settings = true;
            }
            printf("\r\n>>> [LONG PRESS] Settings Menu %s <<<\r\n\r\n", (app_state == APP_STATE_SETTINGS) ? "ENTERED" : "EXITED");
        }

        // --- Read Live Ranging Distance ---
        int live_raw_mm = -1;
        if (vl53_status == VL53LX_ERROR_NONE) {
            if (VL53LX_GetMeasurementDataReady(p_vl53, &vl53_ready) == VL53LX_ERROR_NONE && vl53_ready != 0) {
                if (VL53LX_GetMultiRangingData(p_vl53, &ranging_data) == VL53LX_ERROR_NONE) {
                    int target_mm = Process_ST_MultiTarget_Ranging(&ranging_data);
                    if (target_mm > 0) {
                        live_raw_mm = Filter_ToF_Distance_MM(target_mm);
                        if (app_state == APP_STATE_MEASURE && !hold_active) {
                            last_activity_tick = now; // Active ranging continuously resets sleep timer!
                        }
                    }
                    VL53LX_ClearInterruptAndStartMeasurement(p_vl53);
                }
            }
        }

        if (!hold_active && live_raw_mm >= 0) {
            hold_distance_mm = live_raw_mm;
            hold_pitch_elev  = laser_pitch_elev;
        }

        float active_net_cm = Calculate_Net_Distance_CM(hold_distance_mm, hold_pitch_elev);

        // Update MAX / MIN Continuous Ranging Tracker in MAXMIN Mode (selected_mode == 6)
        if (app_state == APP_STATE_MEASURE && selected_mode == 6 && active_net_cm > 0.0f) {
            if (active_net_cm < min_dist_cm) min_dist_cm = active_net_cm;
            if (active_net_cm > max_dist_cm) max_dist_cm = active_net_cm;
        }

        // --- Handle Press + Twist Chorded Gesture (Switch Held + Encoder Twist -> Global BACK to Main Menu) ---
        if (encoder.press_twist) {
            encoder.press_twist = false;
            app_state = APP_STATE_MENU;
            in_settings = false;
            hold_active = false;
            Reset_Multi_Shot();
            printf("\r\n>>> [PRESS + TWIST GESTURE: GO BACK TO MAIN MENU] <<<\r\n\r\n");
        }
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

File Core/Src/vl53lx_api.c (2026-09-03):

// SPDX-License-Identifier: GPL-2.0+ OR BSD-3-Clause
/******************************************************************************
 * Copyright (c) 2020, STMicroelectronics - All Rights Reserved

 This file is part of VL53LX and is dual licensed,
 either GPL-2.0+
 or 'BSD 3-clause "New" or "Revised" License' , at your option.
 ******************************************************************************
 */






#include "vl53lx_api.h"
#include "vl53lx_register_settings.h"
#include "vl53lx_register_funcs.h"
#include "vl53lx_core.h"
#include "vl53lx_api_calibration.h"
#include "vl53lx_wait.h"
#include "vl53lx_preset_setup.h"
#include "vl53lx_api_debug.h"
#include "vl53lx_api_core.h"
#include "vl53lx_nvm.h"


#define ZONE_CHECK 5

#define LOG_FUNCTION_START(fmt, ...) \
	_LOG_FUNCTION_START(VL53LX_TRACE_MODULE_API, fmt, ##__VA_ARGS__)
#define LOG_FUNCTION_END(status, ...) \
	_LOG_FUNCTION_END(VL53LX_TRACE_MODULE_API, status, ##__VA_ARGS__)
#define LOG_FUNCTION_END_FMT(status, fmt, ...) \
	_LOG_FUNCTION_END_FMT(VL53LX_TRACE_MODULE_API, status, \
			fmt, ##__VA_ARGS__)

#ifdef VL53LX_LOG_ENABLE
#define trace_print(level, ...) \
	_LOG_TRACE_PRINT(VL53LX_TRACE_MODULE_API, \
	level, VL53LX_TRACE_FUNCTION_NONE, ##__VA_ARGS__)
#endif

#ifndef MIN
#define MIN(v1, v2) ((v1) < (v2) ? (v1) : (v2))
#endif
#ifndef MAX
#define MAX(v1, v2) ((v1) < (v2) ? (v2) : (v1))
#endif

#define DMAX_REFLECTANCE_IDX 2



#define LOWPOWER_AUTO_VHV_LOOP_DURATION_US 245
#define LOWPOWER_AUTO_OVERHEAD_BEFORE_A_RANGING 1448
#define LOWPOWER_AUTO_OVERHEAD_BETWEEN_A_B_RANGING 2100

#define FDA_MAX_TIMING_BUDGET_US 550000
#define L4_FDA_MAX_TIMING_BUDGET_US 200000






static int32_t BDTable[VL53LX_TUNING_MAX_TUNABLE_KEY] = {
		TUNING_VERSION,
		TUNING_PROXY_MIN,
		TUNING_SINGLE_TARGET_XTALK_TARGET_DISTANCE_MM,
		TUNING_SINGLE_TARGET_XTALK_SAMPLE_NUMBER,
		TUNING_MIN_AMBIENT_DMAX_VALID,
		TUNING_MAX_SIMPLE_OFFSET_CALIBRATION_SAMPLE_NUMBER,
		TUNING_XTALK_FULL_ROI_TARGET_DISTANCE_MM,
		TUNING_SIMPLE_OFFSET_CALIBRATION_REPEAT,
		TUNING_XTALK_FULL_ROI_BIN_SUM_MARGIN,
		TUNING_XTALK_FULL_ROI_DEFAULT_OFFSET,
		TUNING_ZERO_DISTANCE_OFFSET_NON_LINEAR_FACTOR_DEFAULT
};

static VL53LX_Error ComputeDevicePresetMode(
		VL53LX_DistanceModes DistanceMode,
		VL53LX_DevicePresetModes *pDevicePresetMode);

static VL53LX_Error SetPresetModeL3CX(VL53LX_DEV Dev,
		VL53LX_DistanceModes DistanceMode,
		uint32_t inter_measurement_period_ms);

static int IsL4(VL53LX_DEV Dev);

static VL53LX_Error CheckValidRectRoi(VL53LX_UserRoi_t ROI);


VL53LX_Error VL53LX_GetVersion(VL53LX_Version_t *pVersion)
{
	VL53LX_Error Status = VL53LX_ERROR_NONE;

	LOG_FUNCTION_START("");

	pVersion->major = VL53LX_IMPLEMENTATION_VER_MAJOR;
	pVersion->minor = VL53LX_IMPLEMENTATION_VER_MINOR;
	pVersion->build = VL53LX_IMPLEMENTATION_VER_SUB;

	pVersion->revision = VL53LX_IMPLEMENTATION_VER_REVISION;

	LOG_FUNCTION_END(Status);
	return Status;
}

VL53LX_Error VL53LX_GetProductRevision(VL53LX_DEV Dev,
	uint8_t *pProductRevisionMajor, uint8_t *pProductRevisionMinor)
{
	VL53LX_Error Status = VL53LX_ERROR_NONE;
	uint8_t revision_id;
	VL53LX_LLDriverData_t   *pLLData;

	LOG_FUNCTION_START("");

	pLLData =  VL53LXDevStructGetLLDriverHandle(Dev);
	revision_id = pLLData->nvm_copy_data.identification__revision_id;
	*pProductRevisionMajor = 1;
	*pProductRevisionMinor = (revision_id & 0xF0) >> 4;

	LOG_FUNCTION_END(Status);
	return Status;

}

VL53LX_Error VL53LX_GetDeviceInfo(VL53LX_DEV Dev,
	VL53LX_DeviceInfo_t *pVL53LX_DeviceInfo)
{
	VL53LX_Error Status = VL53LX_ERROR_NONE;
	uint8_t revision_id;
	VL53LX_LLDriverData_t   *pLLData;

	LOG_FUNCTION_START("");

	pLLData =  VL53LXDevStructGetLLDriverHandle(Dev);

	pVL53LX_DeviceInfo->ProductType =
			pLLData->nvm_copy_data.identification__module_type;

	revision_id = pLLData->nvm_copy_data.identification__revision_id;
	pVL53LX_DeviceInfo->ProductRevisionMajor = 1;
	pVL53LX_DeviceInfo->ProductRevisionMinor = (revision_id & 0xF0) >> 4;

	LOG_FUNCTION_END(Status);
	return Status;
}

VL53LX_Error VL53LX_GetUID(VL53LX_DEV Dev, uint64_t *pUid)
{
	VL53LX_Error Status = VL53LX_ERROR_NONE;
	uint8_t fmtdata[8];

	LOG_FUNCTION_START("");

	Status = VL53LX_read_nvm_raw_data(Dev,
			(uint8_t)(0x1F8 >> 2),
			(uint8_t)(8 >> 2),
			fmtdata);
	memcpy(pUid, fmtdata, sizeof(uint64_t));

	LOG_FUNCTION_END(Status);
	return Status;
}



VL53LX_Error VL53LX_SetDeviceAddress(VL53LX_DEV Dev, uint8_t DeviceAddress)
{
	VL53LX_Error Status = VL53LX_ERROR_NONE;
	VL53LX_LLDriverData_t *pdev = VL53LXDevStructGetLLDriverHandle(Dev);
	VL53LX_static_nvm_managed_t  *pdata = &(pdev->stat_nvm);

	LOG_FUNCTION_START("");

	Status = VL53LX_WrByte(Dev, VL53LX_I2C_SLAVE__DEVICE_ADDRESS,
			DeviceAddress / 2);

	pdata->i2c_slave__device_address = (DeviceAddress / 2) & 0x7F;

	LOG_FUNCTION_END(Status);
	return Status;
}


VL53LX_Error VL53LX_DataInit(VL53LX_DEV Dev)
{
	VL53LX_Error Status = VL53LX_ERROR_NONE;
	VL53LX_LLDriverData_t *pdev;
	uint8_t  measurement_mode;

	LOG_FUNCTION_START("");


#ifdef USE_I2C_2V8
	Status = VL53LX_RdByte(Dev, VL53LX_PAD_I2C_HV__EXTSUP_CONFIG, &i);
	if (Status == VL53LX_ERROR_NONE) {
		i = (i & 0xfe) | 0x01;
		Status = VL53LX_WrByte(Dev, VL53LX_PAD_I2C_HV__EXTSUP_CONFIG,
				i);
	}
#endif

	if (Status == VL53LX_ERROR_NONE)
		Status = VL53LX_data_init(Dev, 1);

	if (Status == VL53LX_ERROR_NONE)
		Status = SetPresetModeL3CX(Dev,
			VL53LX_DISTANCEMODE_MEDIUM,
			1000);


	if (Status == VL53LX_ERROR_NONE)
		Status = VL53LX_SetMeasurementTimingBudgetMicroSeconds(Dev,
				33333);

	if (Status == VL53LX_ERROR_NONE) {
		pdev = VL53LXDevStructGetLLDriverHandle(Dev);
		memset(&pdev->per_vcsel_cal_data, 0,
				sizeof(pdev->per_vcsel_cal_data));
	}

	if (Status == VL53LX_ERROR_NONE) {
		Status = VL53LX_set_dmax_mode(Dev,
			VL53LX_DEVICEDMAXMODE__CUST_CAL_DATA);
	}


	if (Status == VL53LX_ERROR_NONE)
		Status = VL53LX_SmudgeCorrectionEnable(Dev,
			VL53LX_SMUDGE_CORRECTION_NONE);

	measurement_mode  = VL53LX_DEVICEMEASUREMENTMODE_BACKTOBACK;
	VL53LXDevDataSet(Dev, LLData.measurement_mode, measurement_mode);

	VL53LXDevDataSet(Dev, CurrentParameters.DistanceMode,
			VL53LX_DISTANCEMODE_MEDIUM);

	LOG_FUNCTION_END(Status);
	return Status;
}


VL53LX_Error VL53LX_WaitDeviceBooted(VL53LX_DEV Dev)
{
	VL53LX_Error Status = VL53LX_ERROR_NONE;

	LOG_FUNCTION_START("");

	Status = VL53LX_poll_for_boot_completion(Dev,
			VL53LX_BOOT_COMPLETION_POLLING_TIMEOUT_MS);

	LOG_FUNCTION_END(Status);
	return Status;
}
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

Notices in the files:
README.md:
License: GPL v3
